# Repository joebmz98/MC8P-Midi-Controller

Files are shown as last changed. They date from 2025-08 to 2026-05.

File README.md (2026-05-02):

# MC8P Standalone MIDI Controller

---

# **8-Pot Standalone MIDI Controller (Teensy 4.0)**

A customizable, open-source MIDI controller with **8 potentiometers**, each supporting **Up to 10 assignable MIDI CCs per Potentiometer**, built around the **Teensy 4.0** for high-performance MIDI control.

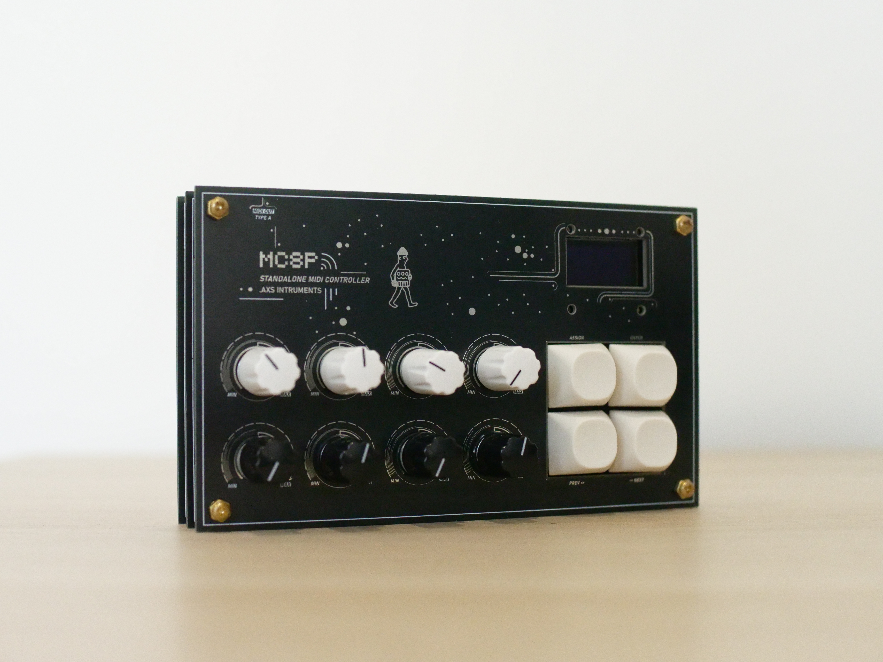
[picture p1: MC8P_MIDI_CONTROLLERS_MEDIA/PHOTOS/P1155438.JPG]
Photo of the assembled MC8P MIDI Controller


---
## Introducing the MC8P Video

Watch the introduction video (https://www.youtube.com/watch?v=sK4E2PJmlkE)
---

## **Features**
- **8x B100K Pots** with smooth analog control
- **Teensy 4.0** for fast, reliable MIDI
- **SSD1306 I2C OLED (128x64)** for the UI
- **Per-Pot CC Assignment** – Each pot can send **10 different MIDI CCs**
- **3.5mm MIDI TRS Out** (PJ307 socket for Type A MIDI)
- **4x Kailh Switches** for UI navigation/configuration
- **Standalone Operation** – No computer needed after setup
- **Open-Source Firmware** (Arduino IDE-compatible)

---

## **Bill of Materials (BOM)**

| Component | Qty | Notes | Links |
|---|-----|---|---|
| Teensy 4.0 | 1 | Main microcontroller | [The Pi Hut (UK)](https://thepihut.com/products/pjrc-teensy-4-0-usb-development-board) |
| SSD1306 OLED (128×64) | 1 | I²C interface | [AliExpress](https://www.aliexpress.com/item/1005006997755041.html) |
| B100K Vertical Potentiometer | 8  | Linear taper | [Example](https://shorturl.at/ZGaz2) |
| 3.5mm Stereo Socket (PJ307) | 1  | MIDI TRS Type A | [Example](https://shorturl.at/lp2T3) |
| Kailh Switches | 4 | For menu navigation | — |
| Kailh Switch Caps | 4 | For Kailh switches | [AliExpress](https://www.aliexpress.com/item/1005006477890497.html) |
| Potentiometer Knobs | 8 | For B100K potentiometers | [AliExpress](https://www.aliexpress.com/item/1005006064249289.html) |
| DC-005 Barrel Jack Socket  | 1 | 5V DC power input | [AliExpress](https://www.aliexpress.com/item/32839712664.html) |
| 10nF Ceramic Capacitors | 8 | Potentiometer filtering | — |
| 10k Resistors | 4 | Pull-down for buttons | — |
| 220Ω Resistors | 2 | For MIDI Circuitry | — |
| 100nF Ceramic Capacitor | 1 | Power rail stabilisation | — |
| 10uF Ceramic Capacitor | 1 | Power rail stabilisation | — |
| 10uF Electrolytic Capacitor| 1 | 5V input stability | — |
| 100uF Electrolytic Capacitor | 1 | Power rail stabilisation | — |

---

## **Available Purchase Options**
**PCB Only** – For custom builds → [**Purchase from my Tindie store**](https://www.tindie.com/products/axsinstruments/diy-mc8p-standalone-midi-controller-pcbs-only/)

---

## **Installation & Setup**
### **1. Flashing the Firmware**
- Install **Arduino IDE + Teensyduino** and other dependencies referenced in the Building from Source section
- Clone this repo and open the `.ino` file in the Arduino IDE
- Select **Teensy 4.0** in Arduino IDE
- Upload the firmware

### **2. Hardware Assembly**
- Refer to the *Build Guide*

### **3. First Boot**
- Power via **USB** on the Teensy or via DC-005 input jack 
- Use the **OLED menu** to assign CCs

---

## **Configuration**

### Button Functions

| Button | Primary Function |
|---|---|
| ASSIGN | Navigate backward, cancel actions, return to previous screens |
| ENTER | Confirm selections, activate temporary override mode |
| PREV | Move up or decrease values |
| NEXT | Move down or increase values |

### Screen Hierarchy

The interface is organized into several screens accessible from the main display:

**MAIN SCREEN** → **MENU** → **SETTINGS** → various configuration screens

### Main Screen

This is your default operating view. The screen displays eight circular indicators, one for each potentiometer, showing current MIDI values (0-127). Each circle fills proportionally to the value being sent.

From the main screen:
- Press **ASSIGN** to open the menu
- Press and hold **ENTER** to activate temporary override mode (the display inverts as visual feedback)

### Temporary Override Mode

When you press and hold ENTER on the main screen, the controller enters temporary override mode. In this mode, all potentiometer adjustments are temporary. When you release ENTER, the controller returns to the stored values and activates catch up mode, where potentiometers must pass through their stored positions before taking control again.

### Menu Screen

Press ASSIGN from the main screen to reach the menu. Use PREV and NEXT to scroll through options:

- **CC assign** – Configure MIDI messages for each potentiometer
- **Settings** – Access device configuration

Press ENTER to select an option, or press ASSIGN to return to the main screen.

### Assign Screen (CC Assign)

This screen lets you configure up to 10 MIDI messages per potentiometer.

**Navigation flow:**
1. Select which potentiometer to edit (flashing number)
2. Select which message slot to edit, or choose Add/Remove
3. Edit individual parameters

**Parameters you can edit for each message:**
- **Channel** – MIDI channel (1-16) or OMNI
- **CC** – Control Change number (0-127)
- **Min Value** – Minimum output value (0-127)
- **Max Value** – Maximum output value (0-127)
- **Direction** – Normal (0-127) or Inverted (127-0)

**Editing values:** When editing a parameter, use potentiometer 8 to smoothly adjust the value across its full range. The selected parameter flashes to indicate edit mode.

**Navigation within Assign Screen:**
- **PREV/NEXT** – Navigate between pots, messages, or Add/Remove buttons
- **ENTER** – Enter edit mode for a parameter, or cycle to the next parameter
- **ASSIGN** – Return to pot selection, or save and exit (confirmation popup appears)

**Add/Remove messages:**
- Navigate to "+ Add" to create a new message (up to 10 per pot)
- Navigate to "- Remove" to delete the selected message (minimum 1 message per pot)

### Settings Screen

From the menu, select Settings to access:

**Assign Settings** – Choose which potentiometer (1-8) to use for editing values in the Assign screen. Use PREV/NEXT to change the selection.

**Display Settings** – Toggle the display inversion between normal and inverted. Press ENTER to enter edit mode, then use PREV or NEXT to toggle between Yes and No. Press ENTER again to save, or ASSIGN to cancel.

**About** – View firmware version and device information.

**Factory Reset** – Restore all settings to default values. A confirmation screen prevents accidental resets.

### Confirmation Popups

When saving changes or performing a factory reset, a popup screen appears asking for confirmation. Use PREV/NEXT to toggle between Y (Yes) and N (No), then press ENTER to confirm or ASSIGN to cancel.

---

## **MIDI Implementation**
- USB MIDI **OR** TRS MIDI Out (3.5mm Type A)
- Up to **10 CC Messages** per potentiometer - further expansion maybe soon!

---

## **Building from Source**
- Requires **Arduino IDE + Teensyduino**
- Libraries:
  - `Adafruit_SSD1306` (OLED)
  - `Adafruit_GFX` (Adafruit UI Design)
  - `MIDI` (MIDI)
  - `ResponsiveAnalogRead` (Potentiometer Smoothing)
  - `Picopixel` (Picopixel Font)

**Owner's Manual:** https://docs.google.com/document/d/1LK1hT5nvRXzgEnc-npS-HN6GpmSG35B1l2-KNDyIfV0/edit?usp=sharing

---

## **License**
**MIT License** – Open-source for personal & commercial use

---

## **Support & Contributions**
- **Issues:** Open a GitHub ticket
- **Custom Requests:** Start a thread in the discussions page or send me an E-mail! axs.instruments@gmail.com
- **Want to improve it?** PRs welcome!
- **Special Thanks:** This project is supported by **PCBWay** who have kindly provided the PCB stock available at the moment

---

## **Acknowledgments**

PCBway very kindly offered to sponsor this project and have sent me some more stock for the shop. Thank you to PCBway for supporting this passion project of mine. Emily from the marketing department reached out to me when I first launched the product and store and very kindly offered to sponsor the project. Both working with them and using their services was really easy. All I needed to do was export my PCB gerber files, drag and drop them on the 'PCB Instant Quote' page and send it off for approval. I received my order a week later and was very happy with the quality of the PCBs. Thank you again PCBway for your support.

You can find their website here: https://www.pcbway.com/

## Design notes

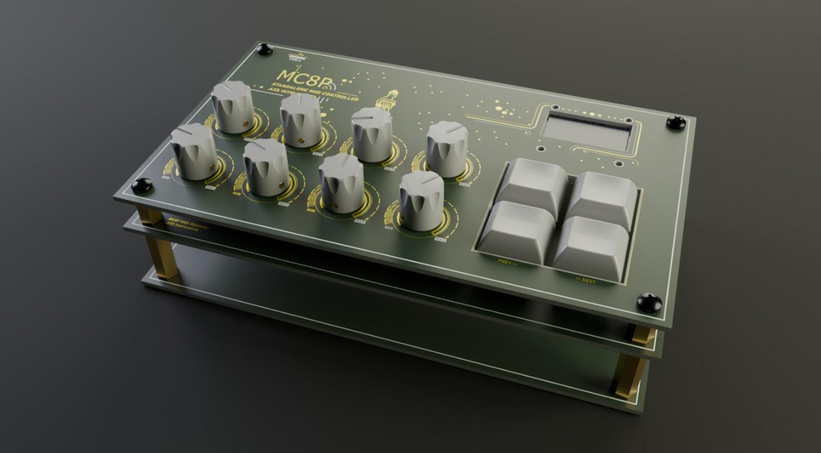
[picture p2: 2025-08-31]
MC8P_MIDI_CONTROLLERS_MEDIA/RENDERS/render_JHazendonk.png

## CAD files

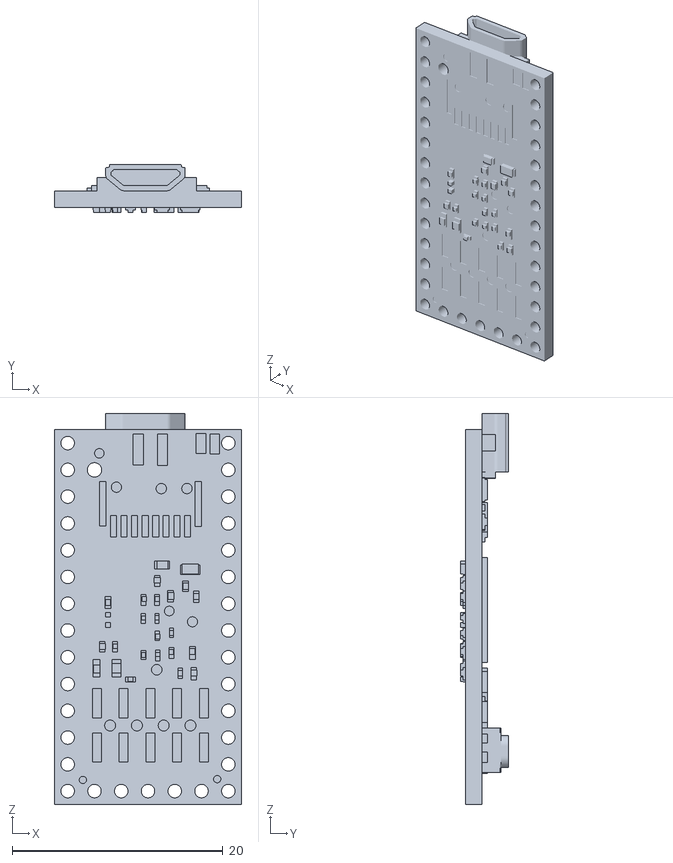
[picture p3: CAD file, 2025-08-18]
MC8P_MIDICONTROLLER_MODELS/EXTERNAL_CAD_FILES/teensy-4-0-2.snapshot.1/Teensy4.0.STL
17.8 x 4.57 x 37.1

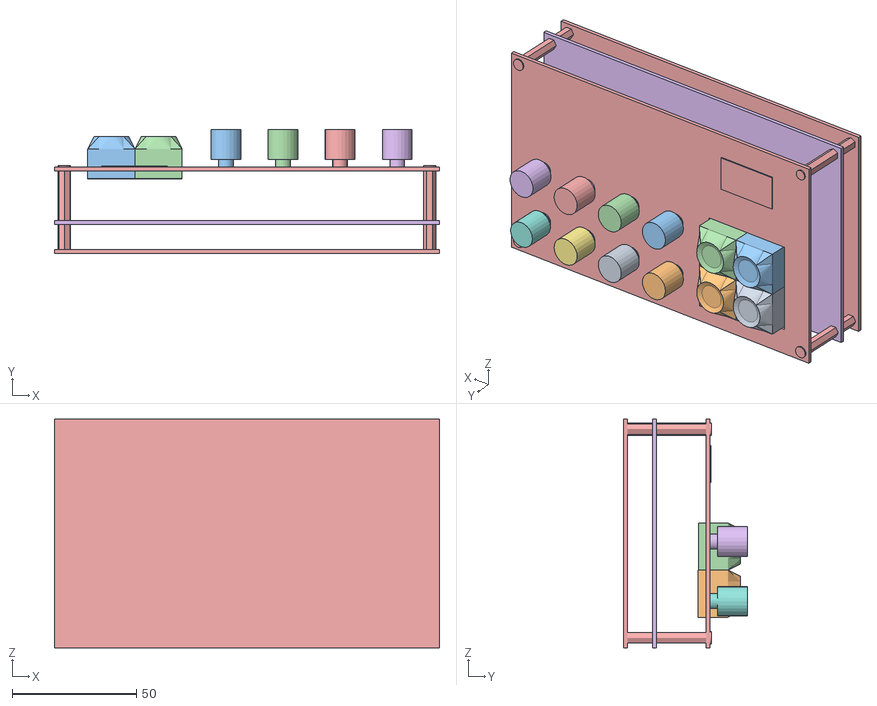
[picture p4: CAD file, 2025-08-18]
MC8P_MIDICONTROLLER_MODELS/MC8P_SKTECHUP.obj
155.0 x 49.8 x 92.0
Mesh1 Group1 Model
Mesh2 Group2 Model
Mesh3 Group3 Model
Mesh4 Group4 Model
Mesh5 Model
Mesh6 Model
Mesh7 Model
Mesh8 Model
Mesh9 Model
Mesh10 Model
Mesh11 Model
Mesh12 Model
Mesh13 Model
Mesh14 Model

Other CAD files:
MC8P_MIDICONTROLLER_MODELS/MC8P_MIDICONTROLLER_MODEL.blend
MC8P_MIDICONTROLLER_MODELS/MC8P_POT_KNOB.blend
MC8P_MIDICONTROLLER_MODELS/MC8P_POT_M3STANDOFFS.blend
MC8P_MIDICONTROLLER_MODELS/MC8P_SKTECHUP.dwg
MC8P_MIDICONTROLLER_MODELS/MC8P_SKTECHUP.dxf
MC8P_MIDICONTROLLER_MODELS/MC8P_SKTECHUP.skp

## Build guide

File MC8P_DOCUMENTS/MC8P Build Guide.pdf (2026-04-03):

## MC8P MIDI Controller - Build Guide .axs instruments

Updated 03/04/2026

Bill of Materials

## MC8P B.O.M

Component | Qty
Teensy 4.0 | 1
Kailh Mechanical Switch | 4
B100k Potentiometer | 8
10k Resistor | 4
220Ω Resistor | 2
10nF Ceramic Capacitor | 8
100nF Ceramic Capacitor | 1
10uF Ceramic Capacitor | 1
10uF Electrolytic Capacitor | 1
100uF Electrolytic Capacitor | 1
128x64 SSD1306 OLED Monochrome Display | 1
PJ307 3.5mm Headphone Socket | 1
DC-005 Barrel Jack socket | 1
M3 10mm (Female-Female) Stand-offs | 4
M3 10mm (Female-Male) Stand-offs | 4
M3 Screws | 4
M3 Nuts | 4
M2 5mm (Female-Male) Stand-offs | 2
M2 Screws | 2
M2 Nuts | 2
KailH Keycaps | 4

M

C

8

P

## B.O.M

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
Build Guide

Smaller components

- Solder resistors to the Main Board: R1–R4 (10k pull-down), R5 & R6 (MIDI Out).
- Solder ceramic capacitors: C1–C12 - NOTE: if electrolytic capacitors inhibit the front panel from fitting on properly, have them at a 90 degree angle.
- Install PJ307 headphone socket (J1).
- Install DC-005 barrel jack socket (J2)

Teensy 4.0

- Solder header pins to Teensy.
- Mount and solder Teensy to the board.

OLED Display (SSD1306)

NOTE: The mounting screws for the OLED aren’t necessary if the pin headers are long enough. You can solder the display in place with the ends of the pin headers being flush with the holes

- Flip board, insert 2× M2 screws through bottom holes.
- Attach female-to-mail M2 stand-offs from front.
- Solder pin headers to the back of OLED.
- Align OLED with stand-offs and header holes.
- Secure with M2 nuts.
- Solder pin headers to Main Board

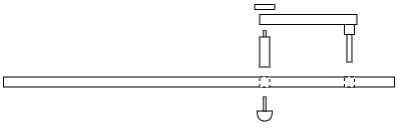
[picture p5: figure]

Switches & Potentiometers

- Solder Kailh switches (SW1–SW4) to the Main Board.
- Solder potentiometers (RV1–RV8) to the Main Board.

Back Panel Assembly

- Insert 4× M2 screws (with nuts screwed on) through back panel holes.
- Attach 4× 10mm M3 female-male stand-offs to the blank side.
- Mount main board and secure with M3 female-female stand-offs.

Front Panel & Final Assembly

- Attach the front panel with remaining M3 screws + nuts.
- Secure potentiometers with washers and nuts.
- Add potentiometer knobs.

That’s it!

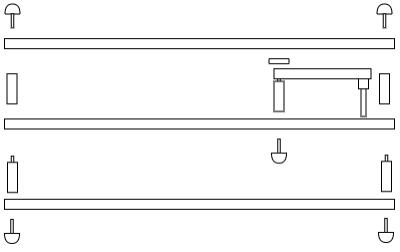
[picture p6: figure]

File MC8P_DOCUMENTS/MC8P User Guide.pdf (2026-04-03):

## MC8P MIDI Controller - Owner’s Manual .axs instruments

## Firmware v2.0

Updated 03/04/2026

Contents

- Introduction
- User Guide
- 1.0 Interface Navigation
- 3.0 Settings
- 3.1 Assign Settings
- 3.2 Display Settings
- 3.3 About page
- 3.4 Factory reset
- A Note of Thanks

Introduction

The MC8P MIDI Controller is a compact, MIDI device designed to enhance hands-on control of the OP-XY by teenage engineering. Featuring 8 fully assignable potentiometers, this controller provides immediate access to all MIDI assigned parameters—reducing menu-diving and streamlining your live performance workflow.

Built around the Teensy 4.0 microcontroller, the MC8P is an open-source project, offering both reliability and customization. I developed this controller out of necessity, seeking a more fluid and intuitive way to manipulate the OP-XY in real time. Whether tweaking filters, modulating effects, or shaping envelopes, the MC8P puts essential controls at your fingertips.

This manual will guide you through setup, configuration, and operation—helping you unlock the full potential of your MC8P.

User Guide

### 1.0 Interface Navigation

The MC8P controller features four buttons for navigation and eight potentiometers for control. The 128x64 OLED display provides visual feedback for all operations.

Buttons:

- ASSIGN - Enter MENU screen, navigate backwards, cancel actions, return to previous screens
- ENTER - Confirm selections, activate TEMP mode in the PERFORMANCE mode
- PREV - Move up in menu screens or decrease values
- NEXT - Move down in menu screens or increase values

### 1.1 Screen Hierarchy

The interface is organized into several screens accessible from the main display:
MAIN SCREEN → MENU → SETTINGS or CC ASSIGN → various configuration screens

### 1.1.1 Main Screen - PERFORMANCE Mode

This is your default operating view. The screen displays eight circular indicators, one for each potentiometer, showing current MIDI values (0-127). Each circle fills proportionally to the value being sent.

From the main screen:

- Press the ASSIGN button to open the menu
- Press and hold the ENTER button to activate temporary override mode (the display inverts as visual feedback)

TEMP Mode
When you press and hold ENTER on the main screen, the controller enters temporary override mode. In this mode, all potentiometer adjustments are temporary. When you release ENTER, the controller returns to the stored values and activates catch up mode, where potentiometers must pass through their stored positions before taking control again.

Use case example:

You can temporarily swell filter cutoffs, resonance, and effects sends to create a rising build-up, then release ENTER to snap everything back to your original mix - all without ever losing your starting point.

Note:

TEMP Mode does not save any changes to your controller’s memory. It is purely for live, non-destructive parameter manipulation.

### 1.1.2 ASSIGN Screen - CC Assign

This screen lets you configure up to 10 MIDI messages per potentiometer.

Navigation flow:

1. Select which potentiometer to edit (flashing number)
2. Select which message slot to edit, or choose Add/Remove
3. Edit individual parameters

Parameters you can edit for each message:

- Channel – MIDI channel (1-16) or OMNI
- CC – Control Change number (0-127)
- Min Value – Minimum output value (0-127)
- Max Value – Maximum output value (0-127)
- Direction – Normal (0-127) or Inverted (127-0)

Editing values: When editing a parameter, use potentiometer 8 to smoothly adjust the value across its full range. The selected parameter flashes to indicate edit mode.

Navigation within Assign Screen:

- PREV/NEXT – Navigate between pots, messages, or Add/Remove buttons
- ENTER – Enter edit mode for a parameter, or cycle to the next parameter
- ASSIGN – Return to pot selection, or save and exit (confirmation popup appears)

Add/Remove messages:

- Navigate to "+ Add" to create a new message (up to 10 per pot)
- Navigate to "- Remove" to delete the selected message (minimum 1 message per pot)

### 1.1.3 Settings Screen

From the menu, select Settings to access:

- Assign Settings – Choose which potentiometer (1-8) to use for editing values in the Assign screen. Use PREV/NEXT to change the selection.
- Display Settings – Toggle the display inversion between normal and inverted. Press ENTER to enter edit mode, then use PREV or NEXT to toggle between Yes and No. Press ENTER again to save, or ASSIGN to cancel.
- About – View firmware version and device information.
- Factory Reset – Restore all settings to default values.

A Note of Thanks

Thank you for purchasing the MC8P MIDI Controller and supporting this passion project of mine! As someone who loves making music and tinkering with hardware, creating this controller has been a deeply rewarding experience and I’m incredibly grateful that you’ve chosen to be part of its journey.

The MC8P was born out of my own need for a more tactile, performance-friendly way to control the OP-XY, and I hope it brings the same fluidity and joy to your setup as it has to mine.

Your Feedback Matters

This is an evolving project, and I’d love to hear from you! If you have ideas for new features, improvements, or just want to share how you’re using the MC8P, please reach out via:

Email: axs.instruments@gmail.com

Instagram: @axs.instruments

GitHub: MC8P Midi Controller (https://github.com/joebmz98/MC8P-Midi-Controller/tree/main)

Your input helps shape future updates, so don’t hesitate to get in touch.

Most of all… have fun! I hope the MC8P becomes an indispensable part of your creative process.

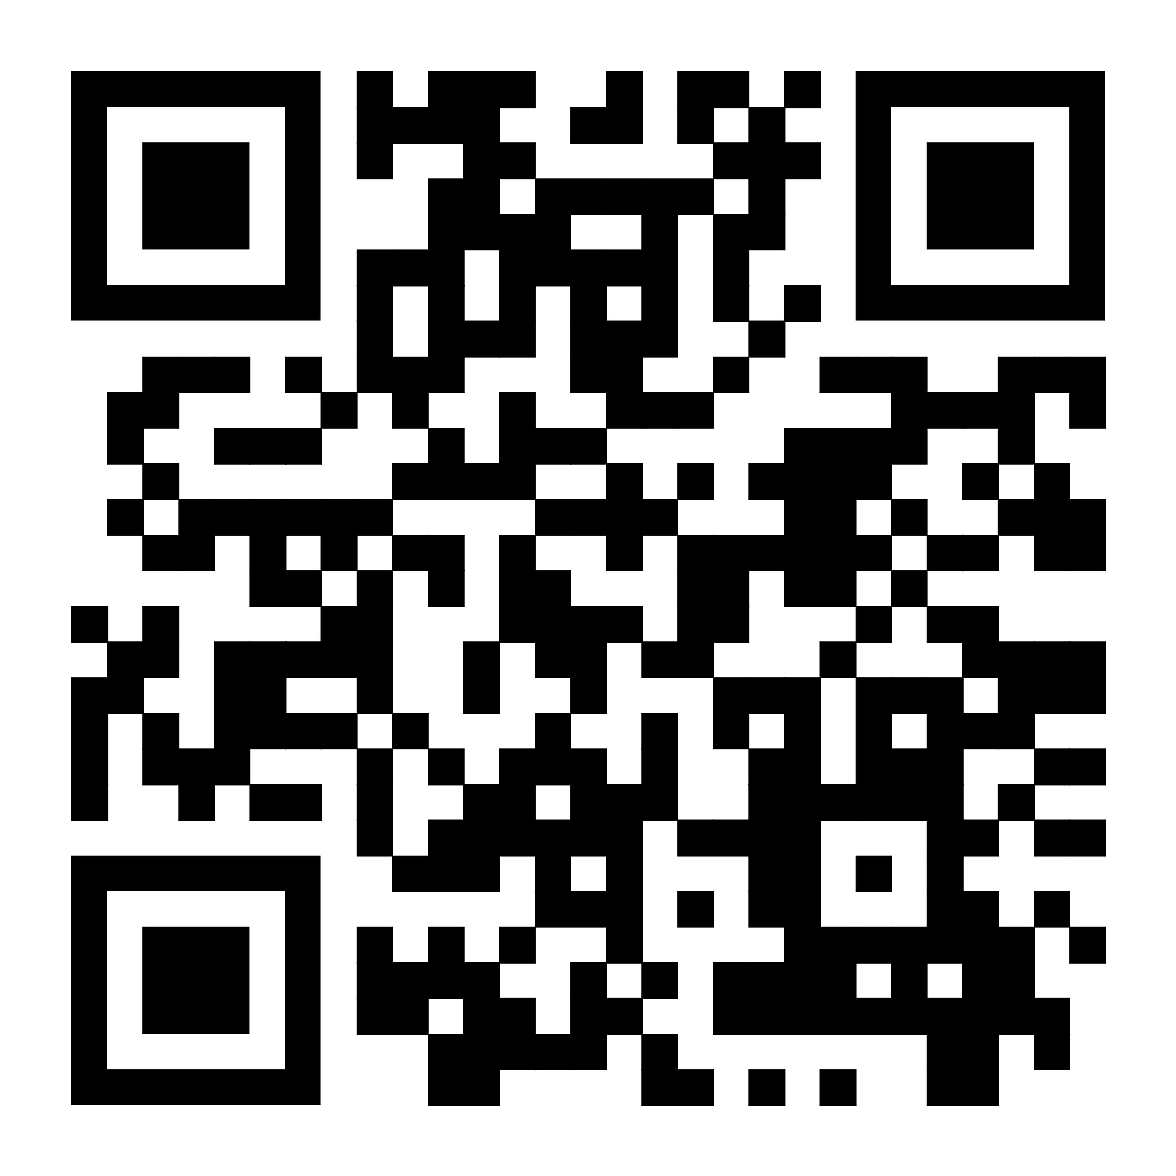
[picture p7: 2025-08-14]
MC8P_MANUAL_QR.png

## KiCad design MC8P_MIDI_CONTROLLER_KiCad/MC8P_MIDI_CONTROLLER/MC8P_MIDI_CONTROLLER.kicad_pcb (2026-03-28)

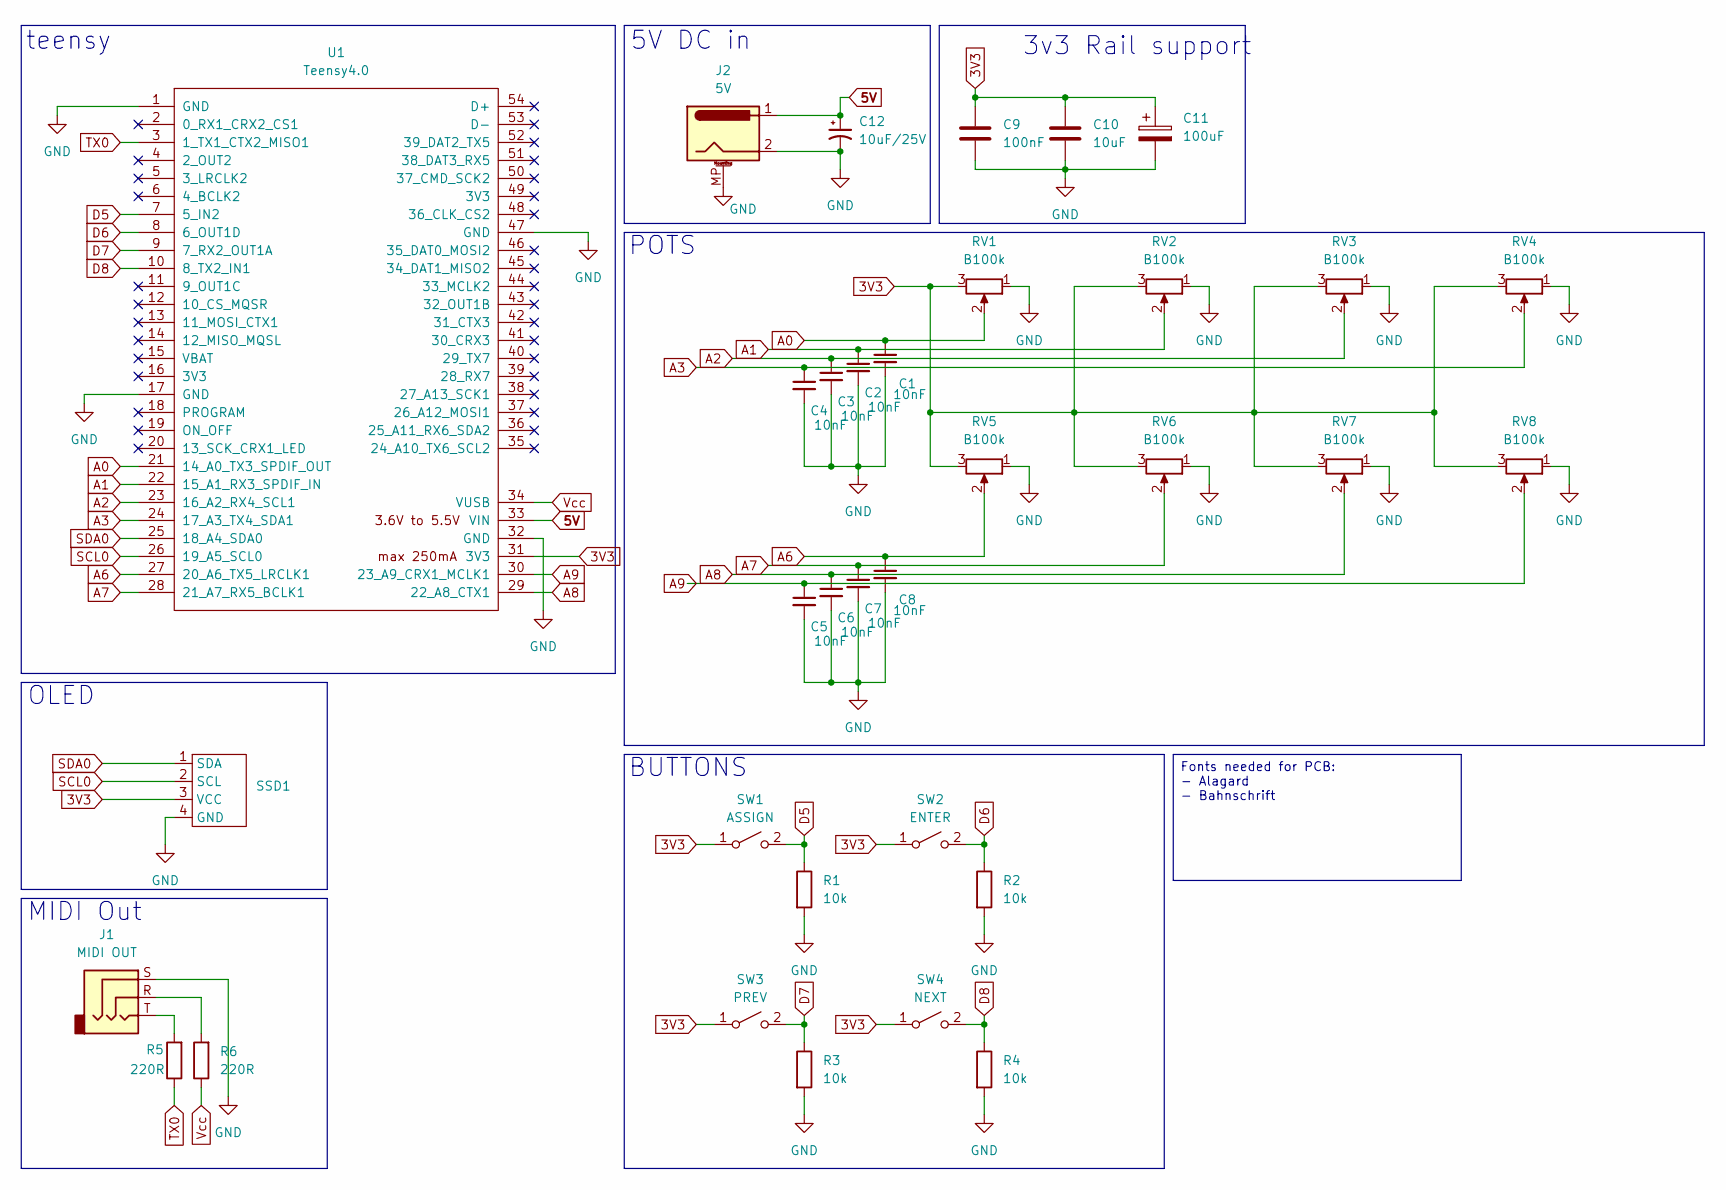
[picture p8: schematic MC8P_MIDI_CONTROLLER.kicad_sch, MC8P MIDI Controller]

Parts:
C1, C2, C3, C4, C5, C6, C7, C8: C_Generic; C_Axial_L3.8mm_D2.6mm_P7.50mm_Horizontal
C9: 100nF; C_Disc_D5.0mm_W2.5mm_P5.00mm
C10: 10uF; C_Disc_D5.0mm_W2.5mm_P5.00mm
C11: 100uF; CP_Radial_D4.0mm_P1.50mm
C12: 10uF_4x5.3_10V; CP_Radial_D4.0mm_P1.50mm; Part Number EEE-FN1A100R; JLCPCB ID C176661
J1: MIDI OUT; Jack_3.5mm_CUI_SJ1-3525N_Horizontal_edit
J2: 5V; BarrelJack_GCT_DCJ200-10-A_Horizontal
R1, R2, R3, R4: 10k; R_Axial_DIN0207_L6.3mm_D2.5mm_P7.62mm_Horizontal; Part Number RT0402FRE0710KL
R5, R6: 220R; R_Axial_DIN0207_L6.3mm_D2.5mm_P7.62mm_Horizontal; Part Number RT0402FRE0710KL
RV1, RV2, RV3, RV4, RV5, RV6, RV7, RV8: B100k; Potentiometer_RV09_BigPads
SSD1: SSD1306_OLED_Module
SW1: ASSIGN; SW_Cherry_MX_1.00u_PCB
SW2: ENTER; SW_Cherry_MX_1.00u_PCB
SW3: PREV; SW_Cherry_MX_1.00u_PCB
SW4: NEXT; SW_Cherry_MX_1.00u_PCB
U1: Teensy4.0; Teensy40

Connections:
3V3: C9.1, C10.1, C11.1, RV1.3, RV2.3, RV3.3, RV4.3, RV5.3, RV6.3, RV7.3, RV8.3, SSD1.3 (VCC), SW1.1 (A), SW2.1 (A), SW3.1 (A), SW4.1 (A), U1.31 (3V3); also elsewhere on the board
5V: C12.1, J2.1, U1.33 (VIN)
A0: C1.1, RV1.2, U1.21 (14_A0_TX3_SPDIF_OUT)
A1: C2.1, RV2.2, U1.22 (15_A1_RX3_SPDIF_IN)
A2: C3.1, RV3.2, U1.23 (16_A2_RX4_SCL1)
A3: C4.1, RV4.2, U1.24 (17_A3_TX4_SDA1)
A6: C8.1, RV5.2, U1.27 (20_A6_TX5_LRCLK1)
A7: C7.1, RV6.2, U1.28 (21_A7_RX5_BCLK1)
A8: C6.1, RV7.2, U1.29 (22_A8_CTX1)
A9: C5.1, RV8.2, U1.30 (23_A9_CRX1_MCLK1)
D5: R1.1, SW1.2 (B), U1.7 (5_IN2)
D6: R2.1, SW2.2 (B), U1.8 (6_OUT1D)
D7: R3.1, SW3.2 (B), U1.9 (7_RX2_OUT1A)
D8: R4.1, SW4.2 (B), U1.10 (8_TX2_IN1)
GND: C1.2, C2.2, C3.2, C4.2, C5.2, C6.2, C7.2, C8.2, C9.2, C10.2, C11.2, C12.2, J1.S, J2.2, J2.3, J2.MP (MountPin), R1.2, R2.2, R3.2, R4.2, RV1.1, RV2.1, RV3.1, RV4.1, RV5.1, RV6.1, RV7.1, RV8.1, SSD1.4 (GND), U1.1 (GND), U1.17 (GND), U1.32 (GND), U1.47 (GND); also elsewhere on the board
unnamed: J1.R, R6.2
unnamed: J1.T, R5.2
SCL0: SSD1.2 (SCL), U1.26 (19_A5_SCL0); also elsewhere on the board
SDA0: SSD1.1 (SDA), U1.25 (18_A4_SDA0); also elsewhere on the board
TX0: R5.1, U1.3 (1_TX1_CTX2_MISO1)
Vcc: R6.1, U1.34 (VUSB)

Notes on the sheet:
BUTTONS
5V DC in
3v3 Rail support
OLED
teensy
POTS
MIDI Out
Fonts needed for PCB: - Alagard - Bahnschrift

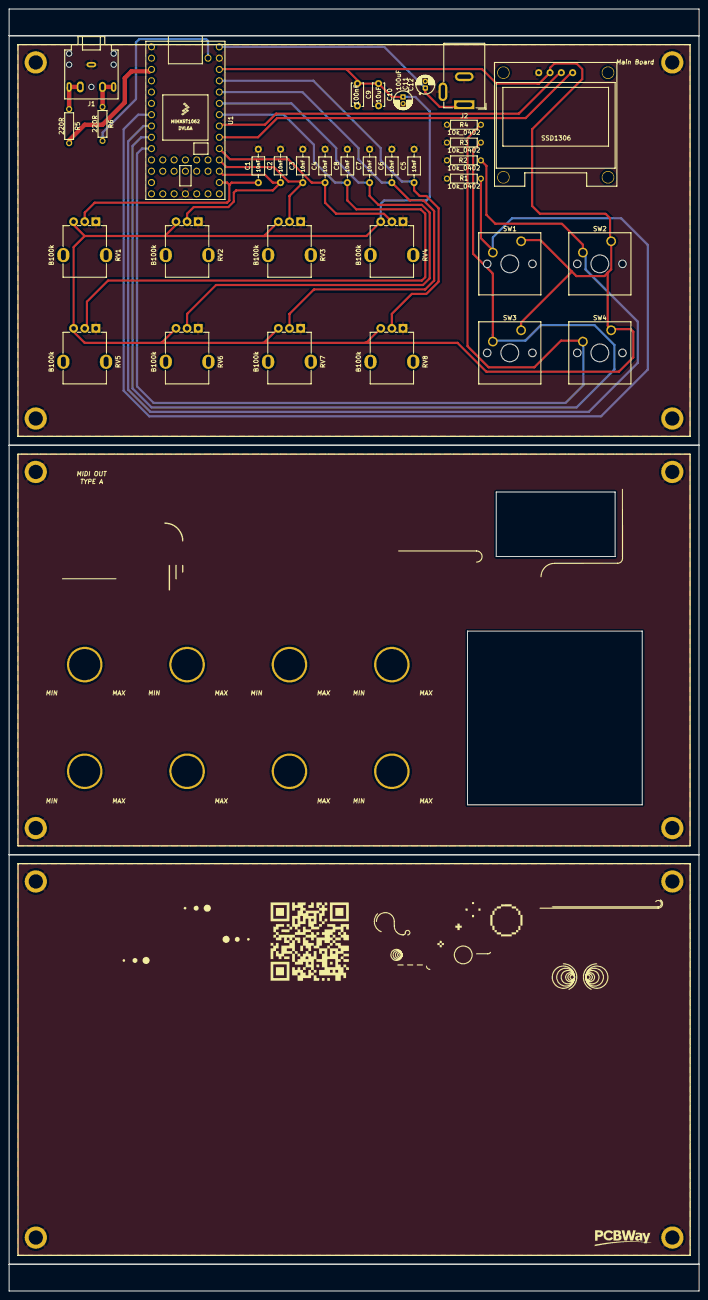
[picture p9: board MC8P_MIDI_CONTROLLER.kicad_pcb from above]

Board: 2 copper layers, 155.0 x 288.0 mm, 34 parts (1 on the bottom side), 21 nets.

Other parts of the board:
SSD1306: SSD1306_OLED_Module

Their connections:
3V3: SSD1306.3 (VCC); also elsewhere on the board
GND: SSD1306.4 (GND); also elsewhere on the board
SCL0: SSD1306.2 (SCL); also elsewhere on the board
SDA0: SSD1306.1 (SDA); also elsewhere on the board

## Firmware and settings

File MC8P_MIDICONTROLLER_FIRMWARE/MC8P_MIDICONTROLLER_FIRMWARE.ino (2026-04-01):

// ********************* //
// MC8P Standalone       //
// MIDI Controller       //
// firmware version 2.0  //
// Hardware Version: 1.0 //
// ********************* //
// controller by         //
// .axs instruments      //
// ********************* //
// Description: 8-potentiometer MIDI controller with
//              programmable CC assignments and
//              multi-message per pot support.
// ********************* //

// ********************* //
// LICENSE & COPYRIGHT
//
// This project is released under the MIT License.
// Copyright (c) 2024 .axs instruments
//
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
// -- LIBRARIES --
#include <Adafruit_SSD1306.h>
#include <Adafruit_GFX.h>
#include <MIDI.h>
#include <ResponsiveAnalogRead.h>
#include <Fonts/Picopixel.h>

// -- USB NAME --
#include <usb_names.h>

// -- FLASH --
#include <EEPROM.h>
#define EEPROM_ADDR 0            // Starting address in EEPROM
#define EEPROM_SIGNATURE 0x55AA  // Signature to verify saved data

// -- OLED SETUP --
#define SCREEN_WIDTH 128
#define SCREEN_HEIGHT 64
#define SCREEN_ADDRESS 0x3C
#define OLED_RESET -1
Adafruit_SSD1306 display(SCREEN_WIDTH, SCREEN_HEIGHT, &Wire, OLED_RESET);

// -- MIDI INSTANCE --
MIDI_CREATE_INSTANCE(HardwareSerial, Serial1, MIDI);  //

// -- FIRMWARE VERSION --
const char* FIRMWARE_VERSION = "2.0";

// STRUCTURE TO HOLD MULTIPLE MIDI MESSAGES PER POT
struct MidiMessageParams {
  byte channel;
  byte cc;
  bool inverted;  // true = inverted (127->0), false = normal (0->127)
  byte minValue;  // Minimum value for CC range (0-127)
  byte maxValue;  // Maximum value for CC range (0-127)
  int value;      // Current stored value
};

// Helper function to map potentiometer value with range and direction
int mapMidiValueWithParams(int rawValue, byte minVal, byte maxVal, bool inverted) {
  // Convert raw potentiometer value (0-1023) to the specified range
  int mappedValue;

  // Handle the range (allow min > max for inverse mapping)
  if (minVal <= maxVal) {
    // Normal range
    mappedValue = map(rawValue, 0, 1023, minVal, maxVal);
  } else {
    // Inverted range (min > max)
    mappedValue = map(rawValue, 0, 1023, maxVal, minVal);
  }

  // Constrain to the valid range
  mappedValue = constrain(mappedValue, min(minVal, maxVal), max(minVal, maxVal));

  // Apply direction inversion if needed
  if (inverted) {
    // Invert the value within the range
    int rangeMin = min(minVal, maxVal);
    int rangeMax = max(minVal, maxVal);
    mappedValue = rangeMin + (rangeMax - mappedValue);
  }

  return mappedValue;
}


// -- BUTTON CONFIG
const int NUM_BUTTONS = 4;
const int BUTTON_PINS[NUM_BUTTONS] = { 5, 6, 7, 8 };
const char* BUTTON_NAMES[NUM_BUTTONS] = { "ASSIGN", "ENTER", "PREV", "NEXT" };
int buttonState[NUM_BUTTONS] = { 0 };
int lastButtonState[NUM_BUTTONS] = { 0 };
unsigned long lastDebounceTime[NUM_BUTTONS] = { 0 };
const unsigned long debounceDelay = 15;  // BUTTON DEBOUNCE

// SCREEN STATE MANAGEMENT
enum ScreenState { MAIN_SCREEN,
                   MENU_SCREEN,
                   ASSIGN_SCREEN,
                   SETTINGS_SCREEN,
                   ASSIGN_SETTINGS_SCREEN,
                   DISPLAY_SETTINGS_SCREEN,
                   ABOUT_SCREEN,
                   RESET_SCREEN,
                   CONFIRM_ASSIGN_SAVE_SCREEN,
                   CONFIRM_RESET_SCREEN };
ScreenState currentScreen = MAIN_SCREEN;

// ASSIGN SCREEN NAVIGATION STATES
enum AssignEditMode {
  ASSIGN_POT_SELECT,      // Selecting which pot to edit
  ASSIGN_MESSAGE_SELECT,  // Selecting which message to edit
  ASSIGN_ADD_REMOVE,      // Selecting Add or Remove button
  ASSIGN_EDIT_CHANNEL,    // Editing channel
  ASSIGN_EDIT_CC,         // Editing CC number
  ASSIGN_EDIT_INVERT,     // Editing invert setting
  ASSIGN_EDIT_MIN,        // Editing min value
  ASSIGN_EDIT_MAX         // Editing max value
};

AssignEditMode assignEditMode = ASSIGN_POT_SELECT;
bool assignEditingMode = false;  // True when editing values, false when selecting

// ASSIGN SETTINGS
int editPotSelection = 7;           // Default to pot 8 (index 7)
bool editingAssignSetting = false;  // Flag for edit mode

// DISPLAY SETTINGS
bool displayInverted = false;        // Default: No
bool editingDisplaySetting = false;  // Flag to indicate we're editing the value
unsigned long editFlashTimer = 0;    // Timer for flashing effect
bool flashState = false;             // Current flash state
bool originalDisplayInverted;        // Store original value when entering edit mode

// MENU NAVIGATION
int selectedMenuItem = 0;  // 0: Assign, 1: States, 2: Settings

// BUTTON STATE MANAGEMENT
// ASSIGN
bool assignButtonHeld = false;
// PREV/NEXT
bool prevButtonPressed = false;
bool nextButtonPressed = false;
// ENTER
bool enterButtonHeld = false;

// POTENTIOMETER CONFIG
const int N_POTS = 8;  // Eight potentiometers
const int POT_PIN[N_POTS] = { A0, A1, A2, A3, A6, A7, A8, A9 };

// MIDI CONFIG
// START-UP CONFIG
byte potChannels[N_POTS] = { 0, 1, 2, 3, 4, 5, 6, 7 };  // Channels 1-8
byte potCCs[N_POTS] = { 7, 7, 7, 7, 7, 7, 7, 7 };       // CC numbers

const int MAX_MESSAGES_PER_POT = 10;                          // Maximum number of messages per pot
MidiMessageParams potMessages[N_POTS][MAX_MESSAGES_PER_POT];  // Array to store messages
byte messageCount[N_POTS] = { 0 };                            // Track how many messages each pot has

// -- ARRAYS TO STORE POT VALUES AND STATES
int potReading[N_POTS] = { 0 };
int potState[N_POTS] = { 0 };
int potPState[N_POTS] = { 0 };
int currentMidiValue[N_POTS] = { 0 };  // Store MIDI values for display

const byte potThreshold = 5;
const int POT_TIMEOUT = 300;
unsigned long pPotTime[N_POTS] = { 0 };
unsigned long potTimer[N_POTS] = { 0 };


float snapMultiplier = 0.01;
ResponsiveAnalogRead responsivePot[N_POTS] = {
  ResponsiveAnalogRead(POT_PIN[0], true, snapMultiplier),
  ResponsiveAnalogRead(POT_PIN[1], true, snapMultiplier),
  ResponsiveAnalogRead(POT_PIN[2], true, snapMultiplier),
  ResponsiveAnalogRead(POT_PIN[3], true, snapMultiplier),
  ResponsiveAnalogRead(POT_PIN[4], true, snapMultiplier),
  ResponsiveAnalogRead(POT_PIN[5], true, snapMultiplier),
  ResponsiveAnalogRead(POT_PIN[6], true, snapMultiplier),
  ResponsiveAnalogRead(POT_PIN[7], true, snapMultiplier)
};

// -- POT SELECTION AND EDITING
int selectedPot = 0;  // Default to pot 0

int selectedMessage = 0;  //

// TEMPORARY MIDI OVERRIDE SYSTEM
bool tempOverrideActive = false;                // Flag for temporary override mode
int originalMidiValues[N_POTS] = { 0 };         // Store original values when ENTER is pressed - INIT TO 0
int tempMidiValues[N_POTS] = { 0 };             // Store temporary values during override - INIT TO 0
unsigned long enterPressTime = 0;               // Time when ENTER was pressed
const unsigned long tempOverrideHoldTime = 20;  // Debounce time to activate override
int postOverridePotPositions[N_POTS] = { 0 };   // Store pot positions when temp override ends - INIT TO 0
bool catchUpActive[N_POTS] = { false };         // Flag to track if catch-up is active for each pot - INIT TO FALSE
int catchUpStartValue[N_POTS] = { 0 };          // MIDI value when catch-up starts - INIT TO 0
int catchUpStartPotPos[N_POTS] = { 0 };         // Pot position when catch-up starts - INIT TO 0

// Add this variable with your other global variables
bool confirmAssignSave = true;  // Track Y/N selection for ASSIGN save confirmation

// EEPROM STRUCTURES
// STRUCTURE TO SAVE MIDI CONFIGURATION TO EEPROM
struct MidiSettings {
  uint16_t signature;
  uint8_t version;
  byte messageCount[N_POTS];
  struct SavedMidiMessage {
    byte channel;
    byte cc;
    bool inverted;
    byte minValue;
    byte maxValue;
    int value;
  } potMessages[N_POTS][MAX_MESSAGES_PER_POT];
};

// STRUCTURE FOR GLOBAL SETTINGS
struct GlobalSettings {
  uint16_t signature;
  uint8_t version;
  bool displayInverted;
  int editPot;
};

// -- EEPROM VERSION
#define SETTINGS_VERSION 2
#define GLOBAL_SETTINGS_VERSION 2

// EEPROM address for global settings
#define GLOBAL_EEPROM_ADDR (EEPROM_ADDR)

// DISPLAY
// MAIN SCREEN DISPLAY CONFIG FOR EACH POT
struct PotDisplay {
  int circleX;
  int circleY;
  int textX;
  int textY;
};

// MAIN SCREEN POT DISPLAY CONFIGURATION
const PotDisplay potDisplays[N_POTS] = {
  { 16, 12, 10, 22 },    // A0
  { 48, 12, 42, 22 },    // A1
  { 80, 12, 74, 22 },    // A2
  { 112, 12, 106, 22 },  // A3
  { 16, 44, 10, 54 },    // A6
  { 48, 44, 42, 54 },    // A7
  { 80, 44, 74, 54 },    // A8
  { 112, 44, 106, 54 }   // A9
};

// CIRCLE POSITION MATRIX LOOK-UP TABLE - ASSIGN SCREEN DISPLAY
const struct {
  int x;
  int y;
} potCirclePositions[N_POTS] = {
  { 102, 8 },   // A0
  { 105, 8 },   // A1
  { 108, 8 },   // A2
  { 111, 8 },   // A3
  { 102, 11 },  // A6
  { 105, 11 },  // A7
  { 108, 11 },  // A8
  { 111, 11 }   // A9
};

// DOT POSITION MATRIX LOOK-UP TABLE - ASSIGN SCREEN DISPLAY
const int POT_MATRIX_POSITIONS[N_POTS][2] = {
  { 102, 7 },   // A0
  { 105, 7 },   // A1
  { 108, 7 },   // A2
  { 111, 7 },   // A3
  { 102, 10 },  // A6
  { 105, 10 },  // A7
  { 108, 10 },  // A8
  { 111, 10 }   // A9
};

// SCROLLING CONFIG
const int MAX_VISIBLE_MESSAGES = 3;  // Number of messages visible at once
int scrollOffset = 0;                // Current scroll position

// DISPLAY BITMAPS
// MAIN_SCREEN
static const unsigned char PROGMEM image_mainScreenInnerLines_bits[] = { 0x00, 0x00, 0x00, 0x02, 0x80, 0x00, 0x00, 0x05, 0x00, 0x00, 0x00, 0x01, 0x40, 0x00, 0x00, 0x00, 0x00, 0x00, 0x00, 0x01, 0x00, 0x00, 0x00, 0x02, 0x00, 0x00, 0x00, 0x00, 0x80, 0x00, 0x00, 0x00, 0x00, 0x00, 0x00, 0x01, 0x00, 0x00, 0x00, 0x02, 0x00, 0x00, 0x00, 0x00, 0x80, 0x00, 0x00, 0x00, 0x00, 0x00, 0x00, 0x01, 0x00, 0x00, 0x00, 0x02, 0x00, 0x00, 0x00, 0x00, 0x80, 0x00, 0x00, 0x00, 0x00, 0x00, 0x00, 0x01, 0x00, 0x00, 0x00, 0x02, 0x00, 0x00, 0x00, 0x00, 0x80, 0x00, 0x00, 0x00, 0x00, 0x00, 0x00, 0x01, 0x00, 0x00, 0x00, 0x02, 0x00, 0x00, 0x00, 0x00, 0x80, 0x00, 0x00, 0x00, 0x00, 0x00, 0x00, 0x01, 0x00, 0x00, 0x00, 0x02, 0x00, 0x00, 0x00, 0x00, 0x80, 0x00, 0x00, 0x00, 0x00, 0x00, 0x00, 0x01, 0x00, 0x00, 0x00, 0x02, 0x00, 0x00, 0x00, 0x00, 0x80, 0x00, 0x00, 0x00, 0x00, 0x00, 0x00, 0x01, 0x00, 0x00, 0x00, 0x02, 0x00, 0x00, 0x00, 0x00, 0x80, 0x00, 0x00, 0x00, 0x00, 0x00, 0x00, 0x01, 0x00, 0x00, 0x00, 0x02, 0x00, 0x00, 0x00, 0x00, 0x80, 0x00, 0x00, 0x00, 0x00, 0x00, 0x00, 0x01, 0x00, 0x00, 0x00, 0x02, 0x00, 0x00, 0x00, 0x00, 0x80, 0x00, 0x00, 0x00, 0x00, 0x00, 0x00, 0x01, 0x00, 0x00, 0x00, 0x02, 0x00, 0x00, 0x00, 0x00, 0x80, 0x00, 0x00, 0x00, 0x00, 0x00, 0x00, 0x01, 0x00, 0x00, 0x00, 0x02, 0x00, 0x00, 0x00, 0x00, 0x80, 0x00, 0x00, 0x00, 0x00, 0x00, 0x00, 0x01, 0x00, 0x00, 0x00, 0x02, 0x00, 0x00, 0x00, 0x00, 0x80, 0x00, 0x00, 0x00, 0x00, 0x00, 0x00, 0x01, 0x00, 0x00, 0x00, 0x02, 0x00, 0x00, 0x00, 0x00, 0x80, 0x00, 0x00, 0x00, 0x00, 0x00, 0x00, 0x01, 0x00, 0x00, 0x00, 0x02, 0x00, 0x00, 0x00, 0x00, 0x80, 0x00, 0x00, 0x00, 0x00, 0x00, 0x00, 0x01, 0x00, 0x00, 0x00, 0x02, 0x00, 0x00, 0x00, 0x00, 0x80, 0x00, 0x00, 0x00, 0x00, 0x00, 0x00, 0x01, 0x00, 0x00, 0x00, 0x02, 0x00, 0x00, 0x00, 0x00, 0x80, 0x00, 0x00, 0x00, 0x00, 0x00, 0x00, 0x01, 0x00, 0x00, 0x00, 0x02, 0x00, 0x00, 0x00, 0x00, 0x80, 0x00, 0x00, 0x00, 0x00, 0x00, 0x00, 0x01, 0x00, 0x00, 0x00, 0x02, 0x00, 0x00, 0x00, 0x00, 0x80, 0x00, 0x00, 0x00, 0x00, 0x00, 0x00, 0x01, 0x00, 0x00, 0x00, 0x02, 0x00, 0x00, 0x00, 0x00, 0x80, 0x00, 0x00, 0x00, 0x00, 0x00, 0x00, 0x01, 0x00, 0x00, 0x00, 0x02, 0x00, 0x00, 0x00, 0x00, 0x80, 0x00, 0x00, 0x00, 0x00, 0x00, 0x00, 0x01, 0x00, 0x00, 0x00, 0x02, 0x00, 0x00, 0x00, 0x00, 0x80, 0x00, 0x00, 0x00, 0x00, 0x00, 0x00, 0x01, 0x00, 0x00, 0x00, 0x02, 0x00, 0x00, 0x00, 0x00, 0x80, 0x00, 0x00, 0x00, 0x00, 0x00, 0x00, 0x01, 0x00, 0x00, 0x00, 0x02, 0x00, 0x00, 0x00, 0x00, 0x80, 0x00, 0x00, 0x00, 0x00, 0x00, 0x00, 0x03, 0x80, 0x00, 0x00, 0x07, 0x00, 0x00, 0x00, 0x01, 0xc0, 0x00, 0x00, 0x00, 0x80, 0x00, 0x00, 0x04, 0x40, 0x00, 0x00, 0x08, 0x80, 0x00, 0x00, 0x02, 0x20, 0x00, 0x00, 0x10, 0x7f, 0xff, 0xff, 0xf9, 0x3f, 0xff, 0xff, 0xf2, 0x7f, 0xff, 0xff, 0xfc, 0x9f, 0xff, 0xff, 0xe0, 0x80, 0x00, 0x00, 0x04, 0x40, 0x00, 0x00, 0x08, 0x80, 0x00, 0x00, 0x02, 0x20, 0x00, 0x00, 0x10, 0x00, 0x00, 0x00, 0x03, 0x80, 0x00, 0x00, 0x07, 0x00, 0x00, 0x00, 0x01, 0xc0, 0x00, 0x00, 0x00, 0x00, 0x00, 0x00, 0x01, 0x00, 0x00, 0x00, 0x02, 0x00, 0x00, 0x00, 0x00, 0x80, 0x00, 0x00, 0x00, 0x00, 0x00, 0x00, 0x01, 0x00, 0x00, 0x00, 0x02, 0x00, 0x00, 0x00, 0x00, 0x80, 0x00, 0x00, 0x00, 0x00, 0x00, 0x00, 0x01, 0x00, 0x00, 0x00, 0x02, 0x00, 0x00, 0x00, 0x00, 0x80, 0x00, 0x00, 0x00, 0x00, 0x00, 0x00, 0x01, 0x00, 0x00, 0x00, 0x02, 0x00, 0x00, 0x00, 0x00, 0x80, 0x00, 0x00, 0x00, 0x00, 0x00, 0x00, 0x01, 0x00, 0x00, 0x00, 0x02, 0x00, 0x00, 0x00, 0x00, 0x80, 0x00, 0x00, 0x00, 0x00, 0x00, 0x00, 0x01, 0x00, 0x00, 0x00, 0x02, 0x00, 0x00, 0x00, 0x00, 0x80, 0x00, 0x00, 0x00, 0x00, 0x00, 0x00, 0x01, 0x00, 0x00, 0x00, 0x02, 0x00, 0x00, 0x00, 0x00, 0x80, 0x00, 0x00, 0x00, 0x00, 0x00, 0x00, 0x01, 0x00, 0x00, 0x00, 0x02, 0x00, 0x00, 0x00, 0x00, 0x80, 0x00, 0x00, 0x00, 0x00, 0x00, 0x00, 0x01, 0x00, 0x00, 0x00, 0x02, 0x00, 0x00, 0x00, 0x00, 0x80, 0x00, 0x00, 0x00, 0x00, 0x00, 0x00, 0x01, 0x00, 0x00, 0x00, 0x02, 0x00, 0x00, 0x00, 0x00, 0x80, 0x00, 0x00, 0x00, 0x00, 0x00, 0x00, 0x01, 0x00, 0x00, 0x00, 0x02, 0x00, 0x00, 0x00, 0x00, 0x80, 0x00, 0x00, 0x00, 0x00, 0x00, 0x00, 0x01, 0x00, 0x00, 0x00, 0x02, 0x00, 0x00, 0x00, 0x00, 0x80, 0x00, 0x00, 0x00, 0x00, 0x00, 0x00, 0x01, 0x00, 0x00, 0x00, 0x02, 0x00, 0x00, 0x00, 0x00, 0x80, 0x00, 0x00, 0x00, 0x00, 0x00, 0x00, 0x01, 0x00, 0x00, 0x00, 0x02, 0x00, 0x00, 0x00, 0x00, 0x80, 0x00, 0x00, 0x00, 0x00, 0x00, 0x00, 0x01, 0x00, 0x00, 0x00, 0x02, 0x00, 0x00, 0x00, 0x00, 0x80, 0x00, 0x00, 0x00, 0x00, 0x00, 0x00, 0x01, 0x00, 0x00, 0x00, 0x02, 0x00, 0x00, 0x00, 0x00, 0x80, 0x00, 0x00, 0x00, 0x00, 0x00, 0x00, 0x01, 0x00, 0x00, 0x00, 0x02, 0x00, 0x00, 0x00, 0x00, 0x80, 0x00, 0x00, 0x00, 0x00, 0x00, 0x00, 0x01, 0x00, 0x00, 0x00, 0x02, 0x00, 0x00, 0x00, 0x00, 0x80, 0x00, 0x00, 0x00, 0x00, 0x00, 0x00, 0x01, 0x00, 0x00, 0x00, 0x02, 0x00, 0x00, 0x00, 0x00, 0x80, 0x00, 0x00, 0x00, 0x00, 0x00, 0x00, 0x01, 0x00, 0x00, 0x00, 0x02, 0x00, 0x00, 0x00, 0x00, 0x80, 0x00, 0x00, 0x00, 0x00, 0x00, 0x00, 0x01, 0x00, 0x00, 0x00, 0x02, 0x00, 0x00, 0x00, 0x00, 0x80, 0x00, 0x00, 0x00, 0x00, 0x00, 0x00, 0x01, 0x00, 0x00, 0x00, 0x02, 0x00, 0x00, 0x00, 0x00, 0x80, 0x00, 0x00, 0x00, 0x00, 0x00, 0x00, 0x01, 0x00, 0x00, 0x00, 0x02, 0x00, 0x00, 0x00, 0x00, 0x80, 0x00, 0x00, 0x00, 0x00, 0x00, 0x00, 0x01, 0x00, 0x00, 0x00, 0x02, 0x00, 0x00, 0x00, 0x00, 0x80, 0x00, 0x00, 0x00, 0x00, 0x00, 0x00, 0x01, 0x00, 0x00, 0x00, 0x02, 0x00, 0x00, 0x00, 0x00, 0x80, 0x00, 0x00, 0x00, 0x00, 0x00, 0x00, 0x01, 0x00, 0x00, 0x00, 0x02, 0x00, 0x00, 0x00, 0x00, 0x80, 0x00, 0x00, 0x00, 0x00, 0x00, 0x00, 0x01, 0x00, 0x00, 0x00, 0x02, 0x00, 0x00, 0x00, 0x00, 0x80, 0x00, 0x00, 0x00, 0x00, 0x00, 0x00, 0x01, 0x00, 0x00, 0x00, 0x02, 0x00, 0x00, 0x00, 0x00, 0x80, 0x00, 0x00, 0x00, 0x00, 0x00, 0x00, 0x01, 0x00, 0x00, 0x00, 0x02, 0x00, 0x00, 0x00, 0x00, 0x80, 0x00, 0x00, 0x00, 0x00, 0x00, 0x00, 0x01, 0x00, 0x00, 0x00, 0x02, 0x00, 0x00, 0x00, 0x00, 0x80, 0x00, 0x00, 0x00, 0x00, 0x00, 0x00, 0x01, 0x00, 0x00, 0x00, 0x02, 0x00, 0x00, 0x00, 0x00, 0x80, 0x00, 0x00, 0x00, 0x00, 0x00, 0x00, 0x02, 0x80, 0x00, 0x00, 0x05, 0x00, 0x00, 0x00, 0x01, 0x40, 0x00, 0x00, 0x00 };
// ASSIGN SCREEN
static const unsigned char PROGMEM image_ctrlMessageIndicator_bits[] = { 0x20, 0x60, 0xe0, 0x60, 0x20 };
static const unsigned char PROGMEM image_potMatrixGrid_bits[] = { 0x92, 0x40, 0x00, 0x00, 0x00, 0x00, 0x92, 0x40 };
static const unsigned char PROGMEM image_valueIndicator_bits[] = { 0xfc };

// ASSIGN PARAMETER EDITING
int selectedAddRemove = 0;     // 0 = Add, 1 = Remove
bool confirmSelection = true;  // Track Y/N selection (true = Yes, false = No)

int lastPot8Value = -1;
unsigned long lastPot8ChangeTime = 0;

// ***************************  //
// SETUP
// ***************************  //
void setup() {

  // BEGIN SERIAL MONITORING
  // SERIAL1 IS FOR MIDI OUTPPUT
  Serial.begin(9600);
  Serial1.begin(31250);
  // -- INIT MIDI
  MIDI.begin();
  Serial1.setTX(1);  // SET MIDI OUTPUT PIN

  // POWER LED
  pinMode(LED_BUILTIN, OUTPUT);
  digitalWrite(LED_BUILTIN, HIGH);

  // INITIALISE
  initController();
}
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

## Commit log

2025-08-14 v.1.0
    - Added KiCad Files
    - Added the Firmware
    [MC8P_MIDI_CONTROLLER.kicad_pcb, MC8P_MIDI_CONTROLLER.kicad_sch]
2025-08-14 V1.0.2
    - KiCad Modifications
    [MC8P_MIDI_CONTROLLER.kicad_pcb]
2025-08-14 v1.0.3
    - Back panel finalised
    - Exported gerbers
    - Panelised for DIY kits
    [MC8P_MIDI_CONTROLLER-B_Cu.gbr, MC8P_MIDI_CONTROLLER-B_Mask.gbr, MC8P_MIDI_CONTROLLER-B_Paste.gbr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]
2025-08-14 Gerber Edits
    [MC8P_MIDI_CONTROLLER-B_Cu.gbr, MC8P_MIDI_CONTROLLER-B_Mask.gbr, MC8P_MIDI_CONTROLLER-B_Paste.gbr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]
2025-08-15 v1.0.4
    - Design update with new logo
    [MC8P_MIDI_CONTROLLER-B_Cu.gbr, MC8P_MIDI_CONTROLLER-B_Mask.gbr, MC8P_MIDI_CONTROLLER-B_Paste.gbr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]
2025-08-18 v1.0.6
    -Adjustments to Front Panel and button positions
    - Beginning Blender Models
    [MC8P_MIDICONTROLLER_MODEL.blend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]
2025-08-18 v1.0.8
    - New model
    [MC8P_SKTECHUP.dwg, MC8P_SKTECHUP.dxf, MC8P_SKTECHUP.obj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]
2025-08-18 v1.0.8
    - First renders
    [MC8P_SKTECHUP.obj, MC8P_SKTECHUP.skp]
2025-08-18 v1.0.9
    - Panel alterations
    - Sketchup alterations
    [MC8P_MIDI_CONTROLLER-B_Cu.gbr, MC8P_MIDI_CONTROLLER-B_Mask.gbr, MC8P_MIDI_CONTROLLER-B_Paste.gbr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]
2025-08-19 v.1.0.10
    - Adding Models for pots
    [MC8P_POT_KNOB.blend]
2025-08-20 v1.0.13
    - Blender models update
    [MC8P_POT_KNOB.blend, MC8P_POT_M3STANDOFFS.blend]
2025-08-22 v1.10
    - UI Vectors
    [MC8P_MIDI_CONTROLLER-B_Cu.gbr, MC8P_MIDI_CONTROLLER-B_Mask.gbr, MC8P_MIDI_CONTROLLER-B_Paste.gbr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]
2025-08-29 v1.1.0
    - PCB Fixes
    - firmware descriptor adjustments
    [MC8P_MIDI_CONTROLLER-B_Cu.gbr, MC8P_MIDI_CONTROLLER-B_Mask.gbr, MC8P_MIDI_CONTROLLER-B_Paste.gbr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]
2025-08-30 Firmware v1.1
    -Button Debounce time adjustments
    -Include MIT Licenser reference
2025-08-30 Schematic update v1.2.0
    - Added Bulk capacitors between the 5V and 3V3 power rails to ground for power stabilisation
    - Added Decoupling capacitor between the power rails and ground for high frequency noise filtering
    [MC8P_MIDI_CONTROLLER.kicad_sch]
2025-09-01 Power stability
    - Added capacitors to add power stability
    - Adjusted Front panel + gerbers
    - Adjusted Main Board + gerbers
    - Re-frabricated panel gerbers
    [MC8P_MIDI_CONTROLLER-B_Cu.gbr, MC8P_MIDI_CONTROLLER-B_Mask.gbr, MC8P_MIDI_CONTROLLER-B_Paste.gbr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]
2025-10-30 PCB Update
    - Fixes power resets/brownouts
    - disconnected POTS, BUTTONS and MIDI OUT from Vin
    - connected POTS & BUTTONS to 3V3
    - connected MIDI OUT to VUSB
    [MC8P_MIDI_CONTROLLER-B_Cu.gbr, MC8P_MIDI_CONTROLLER-B_Mask.gbr, MC8P_MIDI_CONTROLLER-B_Paste.gbr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]
2025-10-30 Schematic & PCB labelling update
    Updated Capacitor labelling (C9-11)
    [MC8P_MIDI_CONTROLLER.kicad_pcb, MC8P_MIDI_CONTROLLER.kicad_sch]
2026-01-24 Firmware 1.2.0
    - Added temporary modify function. Hold the ENTER button in the performance mode to temporarily adjust midi parameters. Upon release, the values will return to their original value. Potentiometers wi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
2026-01-28 v1.3
    - Fixed USB Descriptor
    - Made a variable for changing firmware version
    [MC8P_MIDICONTROLLER_FIRMWARE.ino]
2026-02-12 Menus
    - Added new Menu System
    - Added Display invert settings
    - Display settings save to EEPROM
    [MC8P_MIDICONTROLLER_FIRMWARE.ino]
2026-03-28 PCB Updates
    - Added dedicated 5V Centre Positive power input
    - Added PCBWay logo for sponsor
    - Updated UI Components with new Alagard font
    [MC8P_MIDI_CONTROLLER-B_Cu.gbr, MC8P_MIDI_CONTROLLER-B_Mask.gbr, MC8P_MIDI_CONTROLLER-B_Paste.gbr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]
2026-04-01 v2.0
    Screen bug fixes
    [MC8P_MIDICONTROLLER_FIRMWARE.ino]
2026-04-01 v2.0
    fixed max value button order
    [MC8P_MIDICONTROLLER_FIRMWARE.ino]
2026-04-01 v2.0
    removed old button functions and unused variables from readbuttons()
2026-04-01 v2.0
    - factory reset bug with missing midi messages
    [MC8P_MIDICONTROLLER_FIRMWARE.ino]
2026-04-01 v2.0
    Fixed catchup for TEMP mode
    [MC8P_MIDICONTROLLER_FIRMWARE.ino]
2026-04-01 v2.0
    -Fixed USB Descriptor
    [MC8P_MIDICONTROLLER_FIRMWARE.ino]
2026-04-01 v2.0
    Fixed visual bug in temp mode with pot values
    [MC8P_MIDICONTROLLER_FIRMWARE.ino]
2026-04-13 Scenes
    - Added Scene functionality
    - Using the NEXT/PREV buttons you can navigate between Scenes on the OP-XY. The MIDI CC of the scene change can be changed in the menu
2026-05-06 PCB Rev3
    - STM32F411CEU6 Black Pill with
    W25Q64 flash
    - Added DC Jack for powering externally
    - restructured KiCad Folder
    - Added production folder with BOM
    [MC8P_MIDI_CONTROLLER-B_Cu.gbr, MC8P_MIDI_CONTROLLER-B_Mask.gbr, MC8P_MIDI_CONTROLLER-B_Paste.gbr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]
2026-05-14 PCB revisions
    [JLCPCB_BOM.xls, MC8P_MIDI_CONTROLLER.kicad_pcb, MC8P_MIDI_CONTROLLER.kicad_sch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]
2026-10-16 PCB Updates
2026-10-16 2.2 compiled
    Compiled fw 2.2 for manual upload using Teensy bootloader
2026-10-16 Mk1 PCB

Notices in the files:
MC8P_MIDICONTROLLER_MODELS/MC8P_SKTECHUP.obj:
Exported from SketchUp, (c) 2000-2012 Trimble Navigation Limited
